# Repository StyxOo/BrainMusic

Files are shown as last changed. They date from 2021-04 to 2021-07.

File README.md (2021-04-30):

# This is the complete record of my workings, using EMOTIV to make music
## The goal is to use an EMOTIV headset to play physical instruments

### How?
The EMOTIV headsets commands will be evaluated using node-red. Node-red will communicate with an Arduino board using a serial connection. The arduino will then proceed to manage the hardware which plays the instrument.

### Why?
To enable peolpe who are physically unable to still make music using real instruments. Because music has been an essential part of humanity since forever. And because it can be greatly beneficial for mental health. Also because it's cool.

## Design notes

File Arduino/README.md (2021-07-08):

## Arduino

Here you can find all the arduino sketches which have been created. If you do not know how to work with arduino, have a look at their [getting started section](https://www.arduino.cc/en/Guide).

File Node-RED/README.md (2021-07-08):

## Node-RED

Here you can find all the JSON backups of created flows. Import them as needed. To learn how to import and export flows, please refer to [this guide](https://nodered.org/docs/user-guide/editor/workspace/import-export).  
If you do not know how to work with node-red at all, have a look [here](https://nodered.org/docs/getting-started/).

### Requirements
 - Node.js  v14.16.1
 - NPM      v7.10.0
 - Node-RED v1.3.2
    - node-red-contrib-emotiv-bci   v2.1.2
    - node-red-dashboard            v2.28.2
    - node-red-node-serialport      v0.13.0

### Notes
- ~~Only one flow accessing EMOTIV can be enabled at a time.~~

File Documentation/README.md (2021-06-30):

## A small histrory of what happended when

---

### 19.04.2021
#### Installing of required software:
 - node-red
 - EMOTIV BCI
 - node-red-emotiv-toolbox

---

### 21.04.2021
#### Trying to create a connection between node-red and arduino
 - Connunication will happen via USB serial connection
 - Add node-red-nodes-serialport addon for communication to serial ports
 - Add node-red-dashboard for quick UI testing
 - node-red dashboard [here](http://localhost:1880/ui) when node-red is running
 - Serial connection test
    - See `../Arduino/serial_connetion_test` and `../Node-RED/serial_connection_test.json`
    - Serial connection baud rate 9600 on COM3
        - > COM Port is hardware dependend
    - > Only one software can connect to a serial connection at a time. Do not use Arduinos (or any) serial monitor and node-red at the same time
    - The Arduino repeats the message sent from the node-red dashboard

---

### 26.04.2021
#### Rented the headset
 - Frame, two parts
 - Sensors
 - Liquid
 - Wire
 - USB-Stick
 - Serial Number

#### Headset intro
 - Not more than 8 refreshments per second
 - Realistically 1 thought/second
 - Threshold at about 50
 - Smoothing function -> Failsafe against wrong commands
 - 20-30 training sessions
 - Keep sensors slightly moist
 - Store sensors in packaging
 - Virtual headset in EMOTIV app
 - Live training feedback on
 - Learn commands one by one
 - Small trainings sessions

#### Does EMOTIV work with Linux?
- Beta version for Ununtu
- EMOTIV beta might be more of an alpha0

---

### 27.04.2021
#### Headset training
 - Training commands
 - Makes no sense
 - Testing with second Person
 - Similar results on first approach
 - Feel intense thinking in certain area of brain.
    - > Meditation ?
    - Feels weird. Like flexing a muscle, but with parts of the brain
 - Wearing headset, start at base, adjust left three sensors first
 - Bad connection? More lube -> like oil in a pan
 - Bad eeg? Relax. Breath. Muscle movements can impact the eeg

#### Added a idea tag for issues. To mark potential other projet ideas.

---

### 28.04.2021
#### Headset training
 - Issue connecting the headset bluetooth connetion?
    - Reattach hedset usb-dongle
 - This might be not as easy as I thought..

#### Creating sounds
- Virtual oscillators
    - One per command

#### EMOTIV and node-red
- Client secret and id added in `\\Users\$USER$\.node-red\node_modules\node-red-contrib-emotiv-bci\emotiv-bci`
- Command node not conneting

---

### 29.04.2021
#### Command node
 - Command node was not connecting
 - Reinstalled node-red and bci-toolbox
 - Remove and readd command node

---

### 30.04.2021
#### Buzzer
 - A complete connection between the EMOTIV headset and the arduino board
 - Ardunio sketches can not be updated when node-red is accessing the serial port
 - The Arduino reads serial intput in bytes. ~~One byte per loop.~~ Apparently each integer set by node-red, is received as a string. So 55 is two character. This causes a delay when creating the sounds, as reading the string from the serial port takes time. Therefore the numerical value is converted to a single char ([64 becomes `@`](http://www.asciitable.com)), which is then transmited
 - Arduino circuit backups. Which software?
    - > [Tinkercad](https://www.tinkercad.com)
    - Link to circuit can be found at the top of the appropriate arduino sketch
 - The passive buzzer on the Arduino creates a sound of varying pitch, depending on the commands strength

---

### 03.05.2021
#### Return headset
  - Returned to coworker, email confirmation

#### Learning electrical engineering
 - A few basics to make sure, I know how to work with Arduino again

#### 3D Printing
 - Got access to an old 3d printer
 - Might be useful for parts which play an instrument?
 - Probably needs calibration
   - Follow a [guide](https://teachingtechyt.github.io/calibration.html)? 
   - [x] PID Autotune
   - [x] Extruder E-Steps

---

### 04.05.2021
#### Deconstruction of an old Project
 - Deconstructed the fontys car
 - Learned some more things about electronics
 - Citrus acid can clean clean spills of household battery acid. As battery acid is not an acid but alkaline. [See here for more](https://www.energizer.com/about-batteries/what-is-battery-acid).
 - Looking at [this idea](https://github.com/StyxOo/BrainMusic/issues/1), I think it should be quite doable. Maybe one could have races?

---

### 05.05.2021
#### Arduino Serial
 - Arduino can read many bytes per loop.
 - A demo which reads 4 bytes per loop can be found at `../Ardunio/serial_communication_test`
 - > When testing whith a serial monitor: make sure to not send a newline character in the end. Otherwise the first loop will read the desired output. The second loop will read the newline as remaning byte and will output a newline and whichever the last three characters where.
 - The test is set up to receive 4 characters. According to the four command strengths

---

### 06.05.2021
#### Motor tests
 - Connected a motor to an external power source
   - Potentiometer for ontrolling speed
 - Also connected a stepper motor to the arduino
   - [Like this](https://www.tutorialspoint.com/arduino/arduino_stepper_motor.htm)
   - Steps can be controlled via code

---

### 07.05.2021 - 10.05.2021
#### 3D-Printer calibration
 - Required several times of rebuilding firmware as well as many small prints
 - Steps completed:
   - [x] Frame
   - [x] PID Autotune Nozzle
   - [x] PID Autotune Bed
   - [x] Bed leveling
   - [x] Extruder E-Steps
   - [x] Flow calibration
   - [x] Stepper motor driver current
   - [x] Retraction tuning
   - [x] Temperature tuning
   - [x] Acceleration tuning
   - [ ] Linear advance
      - Not possible with the XY-2 Pro Stepper drivers.

---

### 11.05.2021 - 14.05.2021
#### How can I physically play an instrument
 - I have a bass guitar for testing
 - Strings are quite big and easily accessible
 - How will a mechanism hold?
   - Lego and double sided tape as a base?
 - What will play the strins?
   - An arm?
   - A spinning wheel?
   - How will it take the command strength into account?
 - Using Lego to mock up some ideas

---

### 17.05.2021
#### Meeting
 - Progession on playing instruments
 - If music is completed, have a look at a car project
 - Sensor liquid is now available
   - Can the bottle be refilled?

---

### 18.05.2021
#### 3d Modelling
 - Which software?
   - > [FreeCAD](https://www.freecadweb.org)
 - Getting familiar with the software
 - Trying to model a basic lego block
   - Can be found in `../Models/freeCAD/Block.FCStd`
 - Models are organized in the `../Models` directory
   - `../Models/freeCAD` contains freecad files
   - `../Models/stl` contains the stl files which are used in the Cura slicer for 3D printing

---

### 19.05.2021
#### Connecting hardware with lego
 - How can the existing hardware, motors etc, be connected with lego pieces?
 - Thining about ways to connect the stepper motor
   - Attachment for the stepper motor in `../Models/freeCAD/Stepper_Motor_Connector.FCStd`
   - > Probably need caliphers for more precise measurements
   - Iterating connection design
     - > Measurements are not printed exact by the printer. needs some trial and error to dial in...

---

### 20.05.2021
#### Picking up headset
 - Complete contents as listed in the earlier checklist
 - Liquid bottle can not be easily refilled
   - > Might be possible with a syringe?

#### Mental commands training
 - First commands is always triggered. Trained it too much?

---

### 22.05.2021 - 28.05.2021
#### Set up a proper workspace
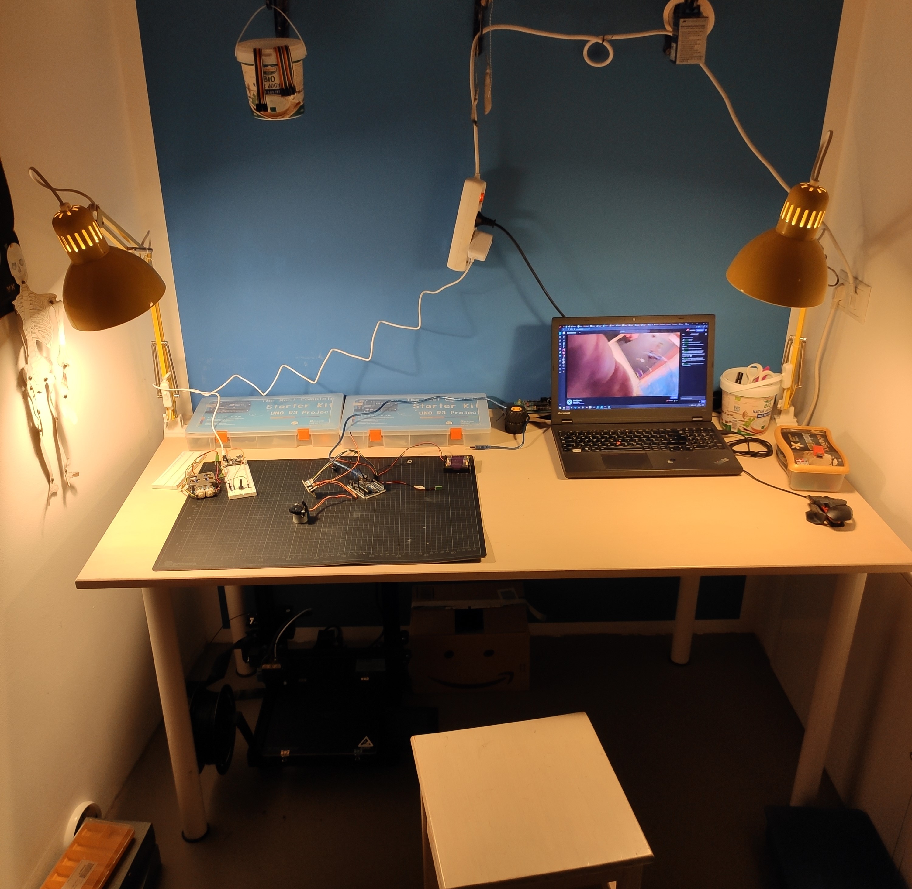
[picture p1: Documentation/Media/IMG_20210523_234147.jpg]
Workspace
 - 

#### Media for documentation
 - All videos and images can be found in the `./Media` directory
 - Some might be not directly used in the documentation. Fell free to snoop around

#### Building hardware
 - The process of creating the hardware is much more tedious than expected.
 - Implementing the electrical motors with lego took more time and attempts than expected
 - The first idea was to print an attachment to a lego axle Attachment
   - Does not work. The axle is not printed exact enough. Furthermore the attachment hole does not have proper dimensions.
 - Trying to dial in the motor attachment dimensions Connectors
 - Connect a lego fitting gear to the motor?
   - Design gear in FreeCAD Gear
   - Printing Printing
   - Check fit Check
   - Rinse and repeat until it fits Gear series
 - The engine needs to be attached to lego pieces
   - Some kind of mount to lego space is needed.
   - Back to FreeCAD Mount
   - How the it works with a gear attached Mounting
 - [It works!!](https://youtu.be/11dx0H1Ohlk)
 - The actual finger is build from lego
  - Allows fast prototyping and iteration
  - [First results seemed promising](https://youtu.be/SAyn8TfC4LA)
  - Some issues with not releasing the string fast enough to create a sound. If the finger pulls stronger, the motor does not provide enough power and gets stuck.
  - [A second motor is added](https://youtu.be/E1cup7A4TuQ)
   - Issues with string release and lack in strength persists
 - Change how motor power is used
   - [Can be seen here](https://youtu.be/ROO-vfrWCQ4)
   - The motor tensions a spring
   - The spring releases a hammer

---

### 31.05.2021 - 27.06.2021
#### Finalizing Hardware
 - Experimented with the number of drops on the driving wheel. Two works, three is too much. The angle becomes too steep.
 - Set up the concept of the second prototype around the bass. And it is able to make the first sounds! [Can be seen here](https://youtu.be/QirRiCVQM7E)
 - Trying to resolve isues with stepper motor power
   - Repinned an adjustable power supply
     - he driver board is rated for 5-12V, the motor for 5V
     - More power makes steps more pronounced
     - Also heats up motor
     - No improvements -> Probably not a power issue
   - Apparently a signal timing issue caused irregulatities
 - Current prototype will not fit on base four times
 - Oriented lenght ways along bass
 - Created a longer driver wheel to move all hammers
 - Proof of concept for one hammer here
   - Relies on rubbers to pull down towards the string, instead fo a big convuluted lego construction
 - All hammers attached to bass like this
 - Sound intensity controlled by servos mounted above
   - Connected to the top of the hammers with a rubber as well
   - Pulling against the rubber below, the intensity can be dialed in
   - Hard to hear on video, but [here it is](https://youtu.be/KiKZ2MzRZEQ)
   - Also adjusted the bass strings height to work for all hammers
  
#### Interface to configure servos
 - The servos controlling the level of sound need to be set up individually. Because each rubber has different proberties, different angles lead to different results
 - Considered setting up servoes through node-red or directly on arduino
   - The servos themselfes do not really have anything to do with node-red, so I decided to do it on the arduino itself
 - Wire up a screen and a few buttons to be able to change settings
   - Troubleshooting weird icons on lcd screen [as seen here](https://youtu.be/Rxcgkt5q_3U)
   - Screen can not be powered from the external power supply. Needs the wavelength as provided by the arduino
 - Clean up wireing
   - Before
   - After
 - Attached Electronics to bass. I decided to use hot glue. It acts as an isolator on the electronics, does not damapge the bass, can be easily removed, but also still holds. Have a look
 - Interface code can be found in `../Arduino/servo_interface`
 - A wireing diagram can be found [here](https://www.tinkercad.com/things/bG4AhXoKbqk-servo-interface)

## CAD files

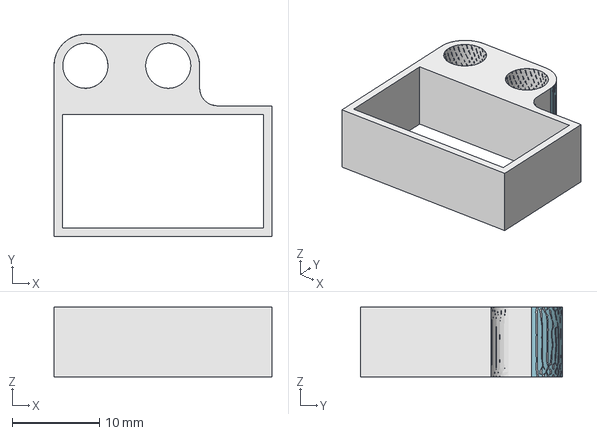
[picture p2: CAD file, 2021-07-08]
Models/freeCAD/Servo_Mount.FCStd
25.0 x 23.2 x 8.00 mm
Pad (Meshed)

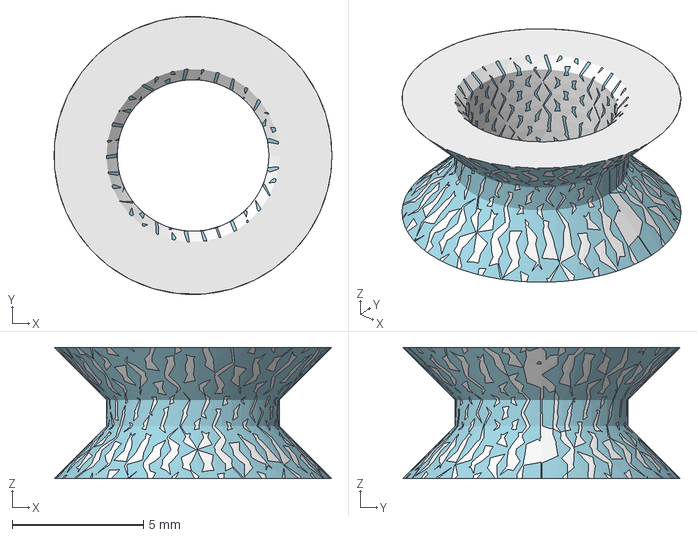
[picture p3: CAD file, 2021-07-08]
Models/freeCAD/Ring.FCStd
10.6 x 10.6 x 5.00 mm
Chamfer (Meshed)

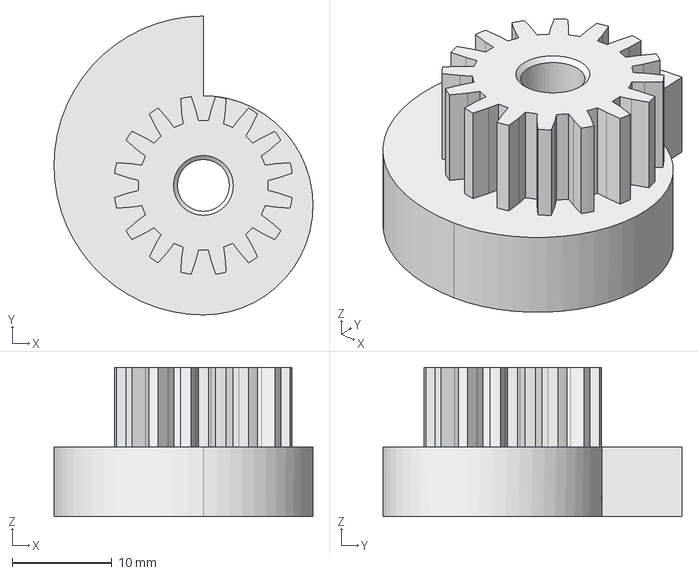
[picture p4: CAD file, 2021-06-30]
Models/freeCAD/Stepper_Motor_Wheel.FCStd
26.0 x 30.0 x 15.0 mm

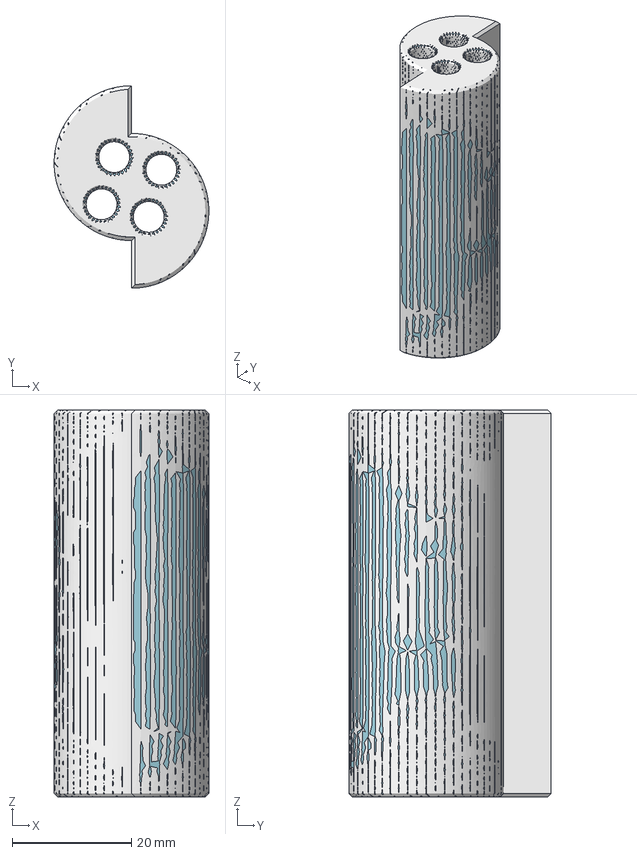
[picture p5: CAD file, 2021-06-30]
Models/freeCAD/Wheel.FCStd
26.0 x 34.0 x 65.0 mm
Chamfer (Meshed)

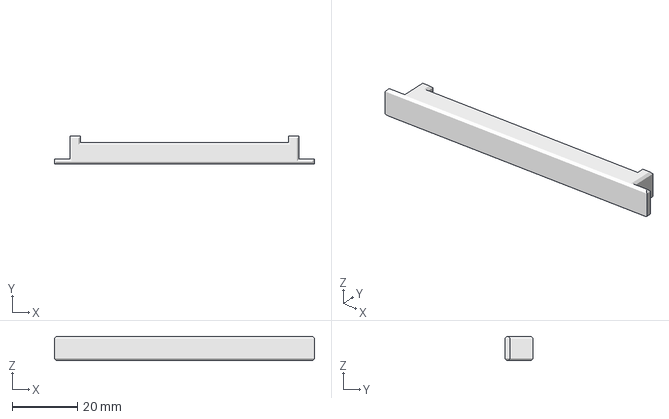
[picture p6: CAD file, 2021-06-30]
Models/freeCAD/Bass_Mount.FCStd
80.0 x 8.50 x 7.50 mm
Chamfer (Meshed)

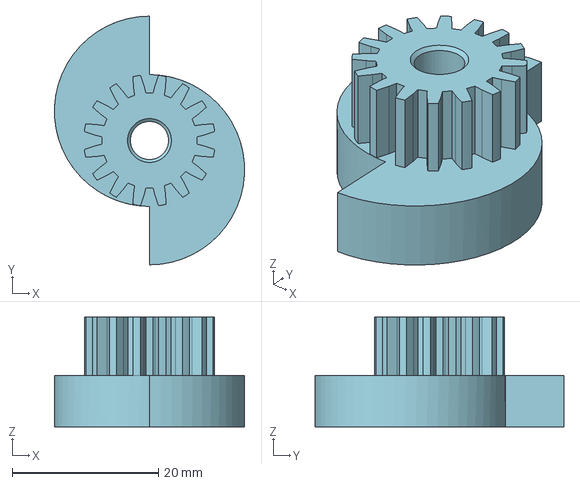
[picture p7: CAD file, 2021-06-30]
Models/freeCAD/Stepper_Motor_Wheel_2.FCStd
26.0 x 34.0 x 15.0 mm

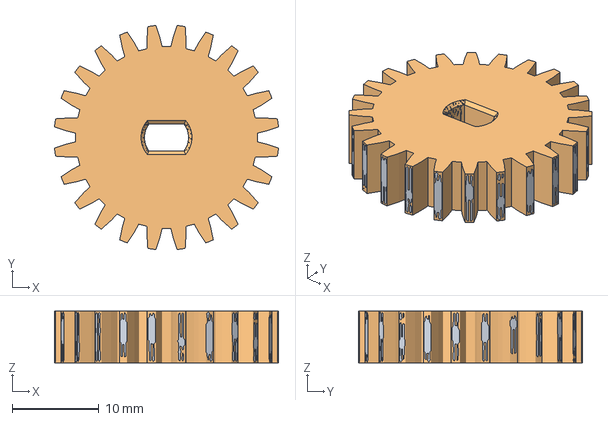
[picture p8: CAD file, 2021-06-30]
Models/freeCAD/Stepper_Motor_Gear.FCStd
25.9 x 25.9 x 6.00 mm
Chamfer (Meshed)

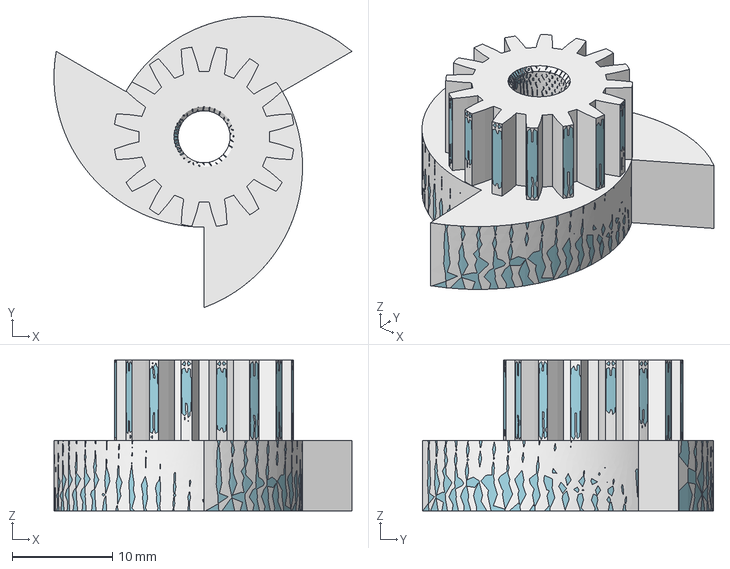
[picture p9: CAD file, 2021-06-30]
Models/freeCAD/Stepper_Motor_Wheel_3.FCStd
29.7 x 29.0 x 15.0 mm
Body (Meshed)

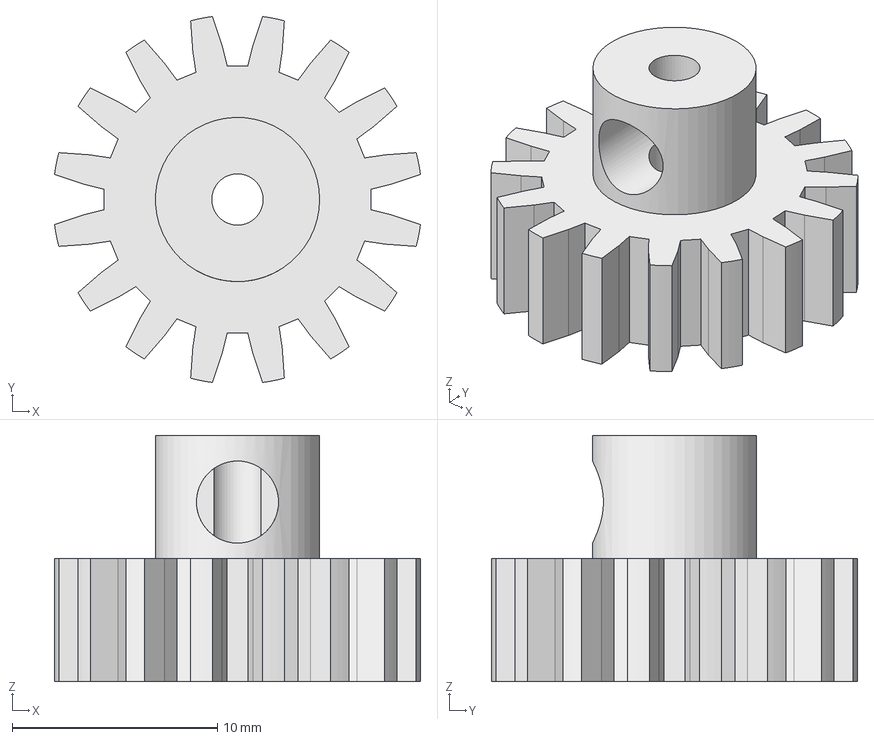
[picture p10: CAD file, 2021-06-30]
Models/freeCAD/Motor_Gear.FCStd
17.8 x 17.8 x 12.0 mm

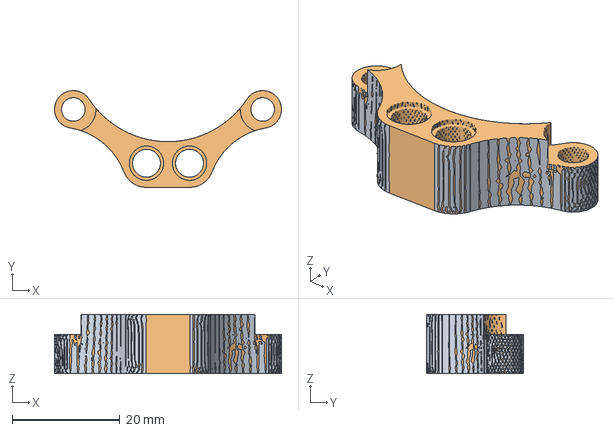
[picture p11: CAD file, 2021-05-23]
Models/freeCAD/Stepper_Motor_Mount.FCStd
42.2 x 18.0 x 11.0 mm
Pocket002 (Meshed)

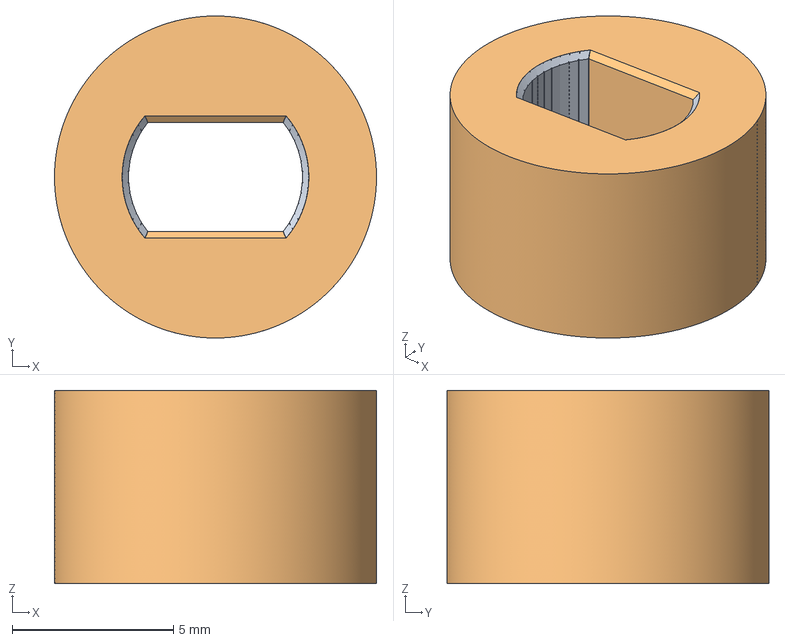
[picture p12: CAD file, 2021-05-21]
Models/freeCAD/Stepper_Motor_Connector.FCStd
10.0 x 10.00 x 6.00 mm
Body (Meshed)

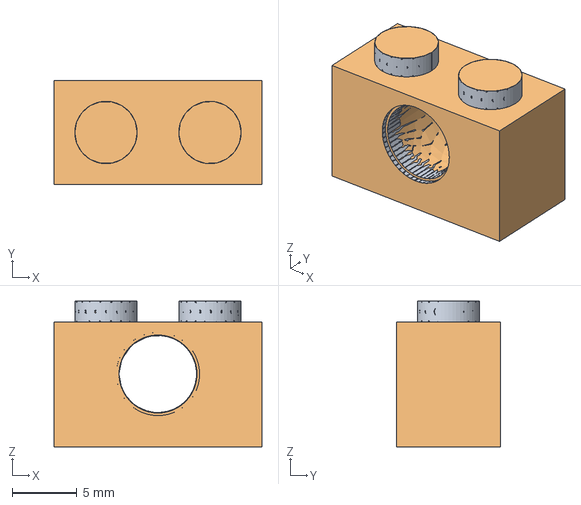
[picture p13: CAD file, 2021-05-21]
Models/freeCAD/Block.FCStd
16.0 x 8.00 x 11.2 mm
Body (Meshed)

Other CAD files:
Models/stl/Bass_Mount.stl
Models/stl/Block.stl
Models/stl/Motor_Gear.stl
Models/stl/Ring.stl
Models/stl/Servo_Mount.stl
Models/stl/Stepper_Motor_Connector.stl
Models/stl/Stepper_Motor_Gear.stl
Models/stl/Stepper_Motor_Mount.stl
Models/stl/Stepper_Motor_Wheel.stl
Models/stl/Stepper_Motor_Wheel_2.stl
Models/stl/Stepper_Motor_Wheel_3.stl
Models/stl/Wheel.stl

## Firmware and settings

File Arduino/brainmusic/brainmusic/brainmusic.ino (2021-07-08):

#include <LiquidCrystal.h>
#include <Servo.h>
#include <Stepper.h>
#define ENTER_BUTTON_PIN 4
#define UP_BUTTON_PIN 3
#define DOWN_BUTTON_PIN 2
#define SERVO_E_PIN 6
#define SERVO_A_PIN 7
#define SERVO_D_PIN 8
#define SERVO_G_PIN 9

LiquidCrystal lcd = LiquidCrystal(A0, A1, A2, A3, A4, A5);
char num[4];
char minMaxString[17];

unsigned long lastPress = 0;
unsigned long buttonDelay = 200;
unsigned long splashTimeout = 10000;
bool splashScreenActive = true;

int enterButtonStateLastTick = 1;
int upButtonStateLastTick = 1;
int downButtonStateLastTick = 1;

int servoValueIndex = 0;
int servoValues [8] = {0,180,0,180,0,180,0,180};

Servo servos[4];
unsigned long lastWrites[4] = {0,0,0,0};
unsigned long writeTimeOut = 500;
int currentServoIndex;

const int stepsPerRevolution = 2048;  // change this to fit the number of steps per revolution
const int rolePerMinute = 17;         // Adjustable range of 28BYJ-48 stepper is 0~17 rpm


Stepper stepperA(stepsPerRevolution, 10,12,11,13);

void writeServo(int index, float value)
{
  unsigned long t = millis();
  if(lastWrites[index] + writeTimeOut < t)
  {
    int pin = SERVO_E_PIN;
    if (index == 1)
    {
      pin = SERVO_A_PIN;
    }
    else if (index == 2)
    {
      pin = SERVO_D_PIN;
    }
    else if (index == 3)
    {
      pin = SERVO_G_PIN;
    }
    servos[index].attach(pin);
  }
  servos[index].write(value);
  lastWrites[index] = t;
}

void detachServos()
{
  unsigned long t = millis();
  for (int i = 0; i < 4; i++)
  {
    if(lastWrites[i] + writeTimeOut < t)
    {
      servos[i].detach();
    }
  }
}

void showSplashScreen() {
  lcd.setCursor(0, 0);
  lcd.print("   Welcome to   ");
  lcd.setCursor(0, 1);
  lcd.print("---BRAINMUSIC---");
  splashScreenActive = true;
}

void updateUI()
{
  int enterButtonState = digitalRead(ENTER_BUTTON_PIN);
  int upButtonState = digitalRead(UP_BUTTON_PIN);
  int downButtonState = digitalRead(DOWN_BUTTON_PIN);
  unsigned long time = millis();
  //Servo current;

  if(lastPress + buttonDelay < time)
  {
    if(enterButtonState < enterButtonStateLastTick)
    {
      if(splashScreenActive)
      {
        lcd.setCursor(0, 0);
        lcd.print("Servo String -X-");
        splashScreenActive = false;
      } 
      else
      {
        servoValueIndex = (servoValueIndex + 1) % 8;
      }

      lcd.setCursor(14, 0);
      if(servoValueIndex < 2)
      {
        lcd.print("E");
        currentServoIndex = 0;
      }
      else if(servoValueIndex < 4)
      {
        lcd.print("A");
        currentServoIndex = 1;
      }
      else if(servoValueIndex < 6)
      {
        lcd.print("D");
        currentServoIndex = 2;
      }
      else
      {
        lcd.print("G");
        currentServoIndex = 3;
      }

      if(servoValueIndex % 2 == 0)
      {
        sprintf(minMaxString, ">Min:%3d Max:%3d", servoValues[servoValueIndex], servoValues[servoValueIndex + 1]);
      } 
      else
      {
        sprintf(minMaxString, " Min:%3d>Max:%3d", servoValues[servoValueIndex - 1], servoValues[servoValueIndex]);
      }
      lcd.setCursor(0,1);
      lcd.print(minMaxString);

      lastPress = time;
    }
    else if(!splashScreenActive && upButtonState < upButtonStateLastTick)
    {
      int value = servoValues[servoValueIndex] + 1;
    
      if(servoValueIndex % 2 == 0)
      {
        if(value >= servoValues[servoValueIndex + 1])
        {
          value--;
        }
      
        lcd.setCursor(5, 1);
      } 
      else
      {
        if(value > 180)
        {
          value = 180;
        }

        lcd.setCursor(13, 1);
      }
    
      servoValues[servoValueIndex] = value;
      //servos[currentServoIndex].write(value);
      writeServo(currentServoIndex, value);
      sprintf(num, "%3d", value);
      lcd.print(num);

      lastPress = time;
    }
    else if(!splashScreenActive && downButtonState < downButtonStateLastTick)
    {
      int value = servoValues[servoValueIndex] - 1;
      if (value < 0)
      {
        value = 0;
      }

      if(servoValueIndex % 2 == 0)
      {
        if (value < 0)
        {
          value = 0;
        }
 
        lcd.setCursor(5, 1);
      } 
      else
      {
        if(value <= servoValues[servoValueIndex - 1])
        {
          value++;
        }
     
        lcd.setCursor(13, 1);
      }
    
      servoValues[servoValueIndex] = value;
      //servos[currentServoIndex].write(value);
      writeServo(currentServoIndex, value);
      sprintf(num, "%3d", value);
      lcd.print(num);

      lastPress = time;
    }
    else if(!splashScreenActive && lastPress + splashTimeout < time)
    {
      showSplashScreen();
    }
  }


  enterButtonStateLastTick = enterButtonState;
  upButtonStateLastTick = upButtonState;
  downButtonStateLastTick = downButtonState;
}


void setup() {
  // put your setup code here, to run once:
  Serial.begin(9600);
   
  // LCD pins
  pinMode(A0, OUTPUT);
  pinMode(A1, OUTPUT);
  pinMode(A2, OUTPUT);
  pinMode(A3, OUTPUT);
  pinMode(A4, OUTPUT);
  pinMode(A5, OUTPUT);

  // Buttons
  pinMode(ENTER_BUTTON_PIN, INPUT_PULLUP);
  pinMode(UP_BUTTON_PIN, INPUT_PULLUP);
  pinMode(DOWN_BUTTON_PIN, INPUT_PULLUP);
  

  lcd.begin(16, 2);
  showSplashScreen();
  for (int i = 0; i < 4; i++)
  {
    writeServo(i, 90);
  }

  stepperA.setSpeed(rolePerMinute);
}

void loop() {
  // put your main code here, to run repeatedly:

  updateUI();
  stepperA.step(-1);
  detachServos();

  if(splashScreenActive)
  {
    if(Serial.available() > 0)
    {
      char buffer[4];
      Serial.readBytes(buffer, 4);
      for(int i = 0; i < 4; i++)
      {
        int value = map(buffer[i], 0, 100, servoValues[i*2], servoValues[i*2 + 1]);
        writeServo(i, value);
      }
      Serial.println(buffer);
    }
  }


/*
  servoD.write(0);
  stepperA.step(-stepsPerRevolution);
  servoD.write(20);
  stepperA.step(-stepsPerRevolution);
  servoD.write(40);
  stepperA.step(-stepsPerRevolution);
  servoD.write(60);
  stepperA.step(-stepsPerRevolution);
  servoD.write(80);
  stepperA.step(-stepsPerRevolution);
  servoD.write(100);
  stepperA.step(-stepsPerRevolution);
  servoD.write(120);
  stepperA.step(-stepsPerRevolution);
  */
}

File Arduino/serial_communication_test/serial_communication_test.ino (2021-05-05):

/*
 * Date:         21.04.2021
 * Author:       Luis Rothenhäusler
 * Description:  This is to figure out how to resonably convey data via serial connection
 *               A four character string is expected. One char for each command.
 *               Do not send a newline character. Otherwise it will be weird.
 */

void setup() {
  // put your setup code here, to run once:
  // Open a serial connection for communication
  Serial.begin(9600);
}

bool newMessage = false;

void loop() {
  // put your main code here, to run repeatedly:
  if(Serial.available() > 0)
  {
    char commands[4];
    Serial.readBytes(commands, 4);
    Serial.println(commands);
    newMessage = true;
  }

  if(newMessage)
  {
    Serial.println("End of current loop after recieving message");
    newMessage = false;
  }
}

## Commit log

2021-04-21 Initial commit
    Contains a test for communication between node-red and an arduino.
2021-04-30 Controll a buzzer with your mind
    [buzzer_test.ino]
2021-05-05 More documentation
    Also the buzzer sounds maximum frequency is now lower..
    [buzzer_test.ino]
2021-05-05 Better understanding of arduino serial
2021-05-20 Basic block stl test file
    [Baustein.stl]
2021-05-21 More updates
    [Block.FCStd, Block.stl, Stepper_Motor_Connector.FCStd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]
2021-05-21 Stepper motor attachment spacing test file
2021-05-21 More attachment tests
    [Stepper_Motor_Connector.FCStd]
2021-05-21 Motor gear test
    [Stepper_Motor_Connector.FCStd]
2021-05-21 More fitting tests
    [Stepper_Motor_Connector.FCStd]
2021-05-21 Final fitting.. maybe
    [Stepper_Motor_Connector.FCStd]
2021-05-21 Chamfer added
    [Stepper_Motor_Connector.FCStd]
2021-05-21 Final gear?
    [Stepper_Motor_Connector.FCStd]
2021-05-22 First mount test
2021-05-22 Mount v2
2021-05-22 Mount v3
    [Stepper_Motor_Mount.FCStd, Stepper_Motor_Mount.stl]
2021-05-22 Mount fin
    [Stepper_Motor_Mount.FCStd, Stepper_Motor_Mount.stl]
2021-05-22 Flipped stud holes
    [Stepper_Motor_Mount.FCStd, Stepper_Motor_Mount.stl]
2021-05-23 Last motor fitting?
    [Stepper_Motor_Mount.FCStd, Stepper_Motor_Mount.stl]
2021-05-23 Mount padding
    [Stepper_Motor_Mount.FCStd, Stepper_Motor_Mount.stl]
2021-05-23 Mount pin hole adjustment
    [Stepper_Motor_Mount.FCStd, Stepper_Motor_Mount.stl]
2021-05-27 Stepper drive wheel
    [Stepper_Motor_Wheel.FCStd, Stepper_Motor_Wheel.stl]
2021-06-30 More parts
    [Bass_Mount.FCStd, Bass_Mount.stl, Motor_Gear.FCStd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]
2021-06-30 Add interface wireing
2021-07-08 Brain Music flow added
2021-07-08 More models and sketches
    [Ring.FCStd, Ring.stl, Servo_Mount.FCStd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]
